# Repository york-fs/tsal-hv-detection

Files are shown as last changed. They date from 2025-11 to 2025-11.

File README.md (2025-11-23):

# TSAL HV Detection Board







Detects if >60 V is present between TS+ and TS- and outputs a 5 V signal (inverted logic for SCS rule compliance).

## Cloning

A recursive clone must be used to download the `kicad-library` repository:

    git clone --recursive https://github.com/york-fs/tsal-hv-detection.git

TSAL_HV

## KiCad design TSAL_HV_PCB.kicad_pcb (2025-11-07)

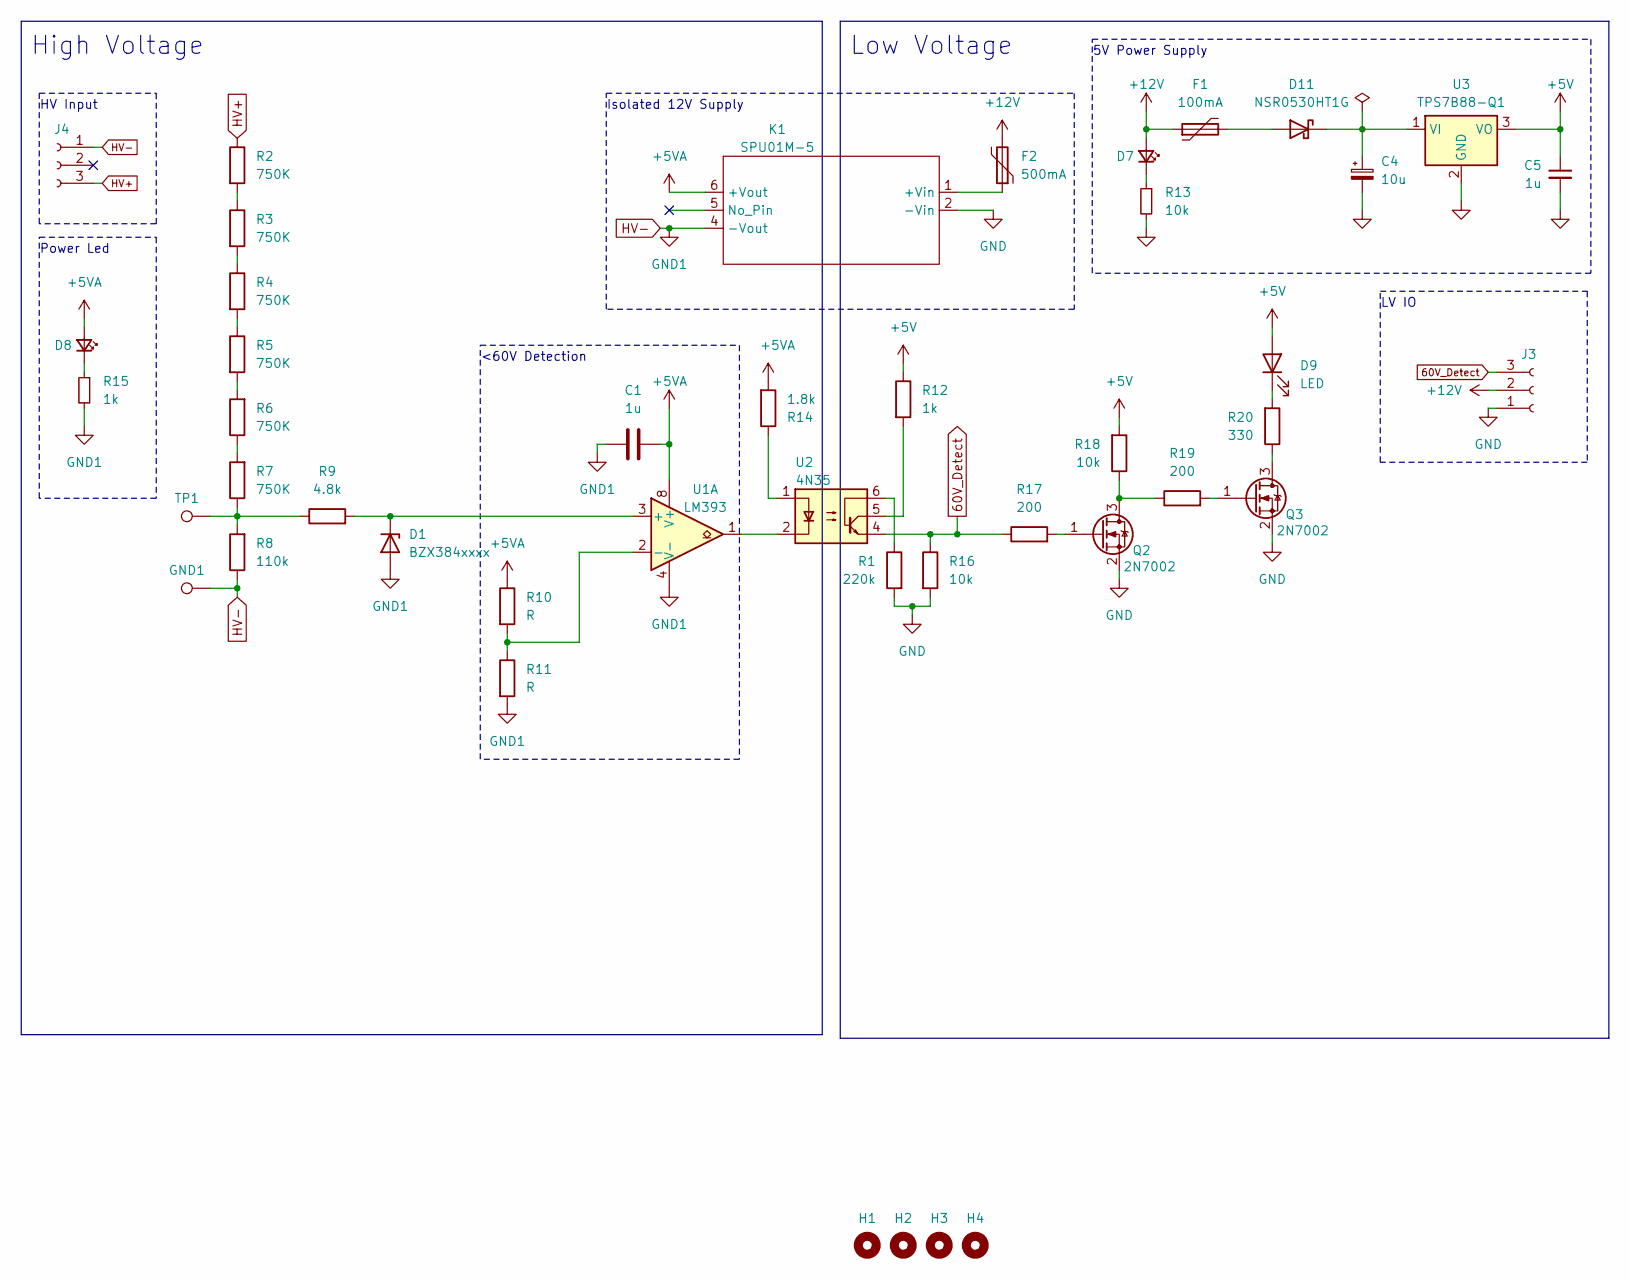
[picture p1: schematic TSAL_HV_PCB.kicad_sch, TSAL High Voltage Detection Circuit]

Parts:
C1, C5: 1u; C_0603_1608Metric
C4: 10u; CP_Elec_6.3x5.4
D1: BZX384xxxx; D_SOD-323
D7, D8: LED_Small; LED_0603_1608Metric
D9: LED; LED_0603_1608Metric
D11: NSR0530HT1G; D_SOD-323
F1: 100mA; R_0805_2012Metric
F2: 500mA; R_0805_2012Metric
GND1: TestPoint; TestPoint_Keystone_5000-5004_Miniature
H1, H2, H3, H4: MountingHole; MountingHole_3.2mm_M3
J3, J4: Conn_01x03_Socket; MolexMicrofitPlus1x3
K1: SPU01M-5
Q2, Q3: 2N7002; SOT-23
R1: 220k; R_0603_1608Metric
R2, R3, R4, R5, R6, R7: 750K; R_1206_3216Metric
R8: 110k; R_1206_3216Metric
R9: 4.8k; R_0603_1608Metric
R10, R11: R; R_0603_1608Metric
R12, R15: 1k; R_0603_1608Metric
R13, R16, R18: 10k; R_0603_1608Metric
R14: 1.8k; R_0603_1608Metric
R17, R19: 200; R_0603_1608Metric
R20: 330; R_0603_1608Metric
TP1: TestPoint; TestPoint_Keystone_5000-5004_Miniature
U1: LM393; SOIC-8_3.9x4.9mm_P1.27mm
U2: 4N35; DIP-6_W7.62mm
U3: TPS7B88-Q1; TO-252-2

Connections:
60V_Detect: J3.3, R16.1, R17.1, U2.4
+5V: C5.1, D9.2 (A), R12.1, R18.2, U3.3 (VO)
+5VA: C1.2, D8.2 (A), K1.6 (+Vout), R10.1, R14.2, U1.8 (V+)
+12V: D7.2 (A), F1.1, F2.2, J3.2
GND: C4.2, C5.2, J3.1, K1.2 (-Vin), Q2.2 (S), Q3.2 (S), R1.2, R13.2, R16.2, U3.2 (GND)
HV+: J4.3, R2.1
HV-: C1.1, D1.2 (A), GND1.1, J4.1, K1.4 (-Vout), R8.1, R11.2, R15.2, U1.4 (V-)
unnamed: D1.1 (K), R9.2, U1.3 (+)
unnamed: D7.1 (K), R13.1
unnamed: D8.1 (K), R15.1
unnamed: D9.1 (K), R20.2
unnamed: D11.2 (A), F1.2
unnamed: C4.1, D11.1 (K), U3.1 (VI)
unnamed: F2.1, K1.1 (+Vin)
unnamed: Q2.3 (D), R18.1, R19.1
unnamed: Q2.1 (G), R17.2
unnamed: Q3.3 (D), R20.1
unnamed: Q3.1 (G), R19.2
unnamed: R1.1, U2.6
unnamed: R2.2, R3.1
unnamed: R3.2, R4.1
unnamed: R4.2, R5.1
unnamed: R5.2, R6.2
unnamed: R6.1, R7.2
unnamed: R7.1, R8.2, R9.1, TP1.1
unnamed: R12.2, U2.5
unnamed: R14.1, U2.1
unnamed: U1.1, U2.2
unnamed: R10.2, R11.1, U1.2 (-)

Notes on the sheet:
Isolated 12V Supply
LV IO
High Voltage
HV Input
<60V Detection
5V Power Supply
Power Led
Low Voltage

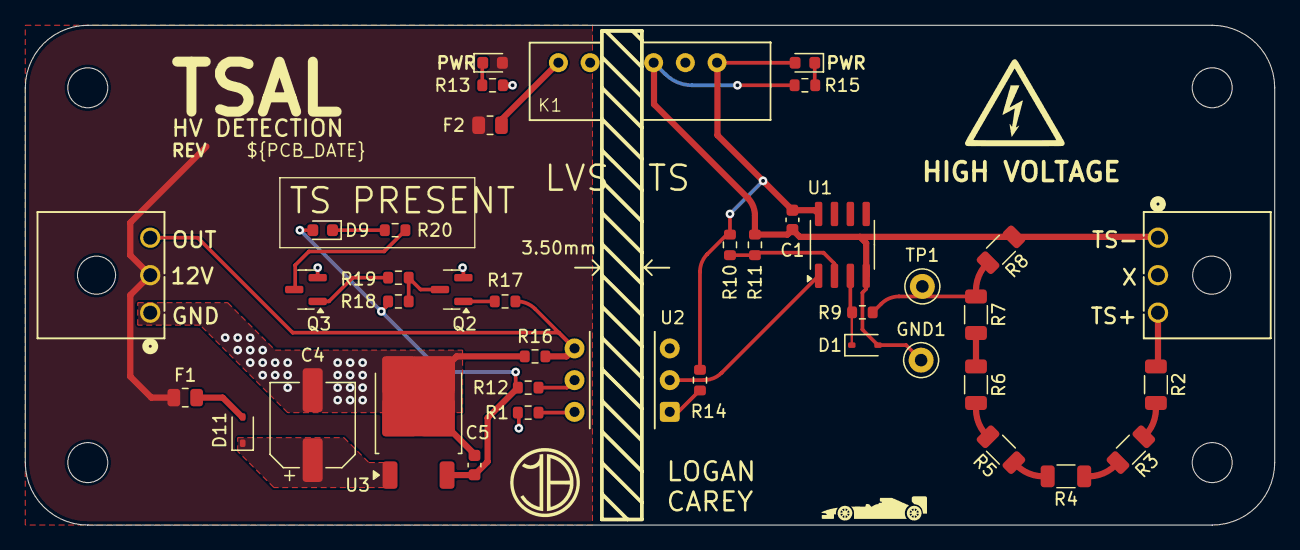
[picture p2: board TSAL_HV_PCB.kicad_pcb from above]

Board: 2 copper layers, 100.0 x 40.0 mm, 44 parts (0 on the bottom side), 29 nets.

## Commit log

2025-11-07 *: Add series resistor and pull-down to optocoupler BJT
    The series resistor protects against shorts on the output and the base
    pull-down helps with noise immunity.
    [TSAL_HV_PCB.kicad_pcb, TSAL_HV_PCB.kicad_sch]
2025-11-23 ci: Add kicad workflow
